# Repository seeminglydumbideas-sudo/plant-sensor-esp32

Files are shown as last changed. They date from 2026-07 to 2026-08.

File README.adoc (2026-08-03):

= plant-sensor-esp32

A low-power Bluetooth Low Energy (BLE) soil moisture sensor node built for the *Seeed Studio XIAO ESP32-C3*.

== Overview

`plant-sensor-esp32` periodically measures soil moisture levels, monitors battery voltage and power source, and broadcasts telemetry over BLE manufacturer advertisements. Designed for battery-powered deployment, the device spends most of its life in ESP32 deep sleep, waking up to sample sensors and advertise data to central receiver nodes (such as the Plant Server).

IMPORTANT: sensors are supposed to be used with a dedicate base station (not used directly with phones). see (todo: link to server ref)

=== Hardware Components

* *Microcontroller:* Seeed Studio XIAO ESP32-C3 (RISC-V single-core @ 160MHz, 2.4GHz Wi-Fi & BLE 5.0)
* *Soil Moisture Sensor:* Capacitive Soil Moisture Sensor v1.2
* *Power Monitoring:* Voltage divider (2x 220kΩ resistors) connected to ADC pin `D2` / `A2`
* *Power Supply:* 3.7V LiPo / Li-Ion battery or USB-C (5V)

== Key Features

* *BLE Telemetry Broadcast:* Broadcasts sensor telemetry without requiring active connections. Scan response manufacturer data payload includes:
** Moisture percentage (`0–100%`, or uncalibrated indicator `0xFF`)
** Raw ADC reading, `rawMin`, and `rawMax` bounds
** Battery voltage (`V`) and power source (Battery vs. USB)
** RTC boot counter
** Filterable by Service UUID `a1b2c3d4-0001-4c9a-8f2e-5a7b9e3d6f80`
* *Capacitive Moisture Sampling:* Non-blocking async sampling state machine to power and sample the sensor safely. Automatically tracks calibration bounds and persists them to NVS flash (`Preferences`).
* *Smart Power Management:* Reads battery voltage via resistor divider on ADC pin `D2`, differentiates between USB and battery power, and controls ESP32 deep sleep cycles. Features a 2-minute safety window on cold power-on to allow seamless firmware reflashing.
* *Calibration Reset:* Press and hold the onboard *BOOT* button (GPIO 9) for 3 seconds to clear saved calibration bounds from flash memory.

== Pinout & Hardware Configuration

[cols="1,1,2", options="header"]
|===
| Component | Pin | Notes

| *Moisture Sensor VCC*
| `D0`
| Switched output to power sensor only during sampling

| *Moisture Sensor Signal*
| `D1`
| Analog input for moisture sensor reading

| *Battery Divider ADC*
| `D2` / `A2`
| Resistor divider input for voltage measurement

| *BOOT Button*
| `GPIO 9`
| Pulled HIGH internally; hold 3s to reset calibration
|===

== Calibration Procedure

The sensor uses automatic bound tracking to calculate soil moisture percentages from raw ADC readings. The bounds (`rawMin` and `rawMax`) are stored in NVS flash memory (`Preferences`). It will persist resets and re-deploy.

To calibrate a sensor:

1. *Wake Device:* Press the *RST button* (or power-cycle the board) to ensure the ESP32 is awake and not in deep sleep mode.
2. *Reset Calibration:* Press and hold the onboard *BOOT button (GPIO 9)* for 3 seconds. The serial output will log `[INFO] Moisture calibration reset`, clearing stored bounds (`rawMin = 4095`, `rawMax = 0`).
3. *Set Dry Bound (0%):* Expose the capacitive probe to dry air (or insert into completely dry soil) during a sample cycle (typically 2-4 minutes). The highest ADC value measured will automatically be saved as `rawMax`.
4. *Set Wet Bound (100%):* Submerge the probe in water up to the max fill line (or insert into fully saturated soil) during a sample cycle. The lowest ADC value measured will automatically be saved as `rawMin`.
5. *Automatic Calculation:* Once `rawMax > rawMin + 500`, the firmware calculates moisture as:
+
[source,cpp]
----
moisture % = 100 - ((100 * (rawValue - rawMin)) / (rawMax - rawMin))
----
+
Updated calibration bounds are saved to flash memory automatically whenever new minimums or maximums are detected.

== Build & Deployment

Use the provided `deploy.sh` script to compile, upload, and monitor:

[source,bash]
----
# Compile and upload specifying the SENSOR_ID
SENSOR_ID=13_rez_ficus ./deploy.sh /dev/ttyACM0

# Compile only
SENSOR_ID=13_rez_ficus ./deploy.sh --compile-only
----

The script automatically generates `Secrets.cpp` containing your specified `SENSOR_ID` and attaches to the serial monitor.

== License

This project is licensed under the MIT License - see the link:LICENSE[LICENSE] file for details.

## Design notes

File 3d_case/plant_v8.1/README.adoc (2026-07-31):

== Plant Sensor V8.1 

* sensor.scad
** moved esp32 3mm down to make the whole smaller
** moved antenna only 2mm down since place due to cable
* holes.scad
** adapt for esp32 new position
* main.scad
** many to adapt to smaller volume

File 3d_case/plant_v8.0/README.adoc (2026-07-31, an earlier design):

== Plant Sensor V8.0

* printed at fablab 21.7.2026
* a bit "bulky", perhaps due to the color (transparent filament)
* once clipped (no screw), hard to take apart due to the screw part to tights.
* plenty space for cables -> can be redude
* sensor a little bit loose -> but differences between PCBs.
* insert walls is hard enough (0.7mm, good) -> wall can be reduced
* evtl. missing guides for antenna?

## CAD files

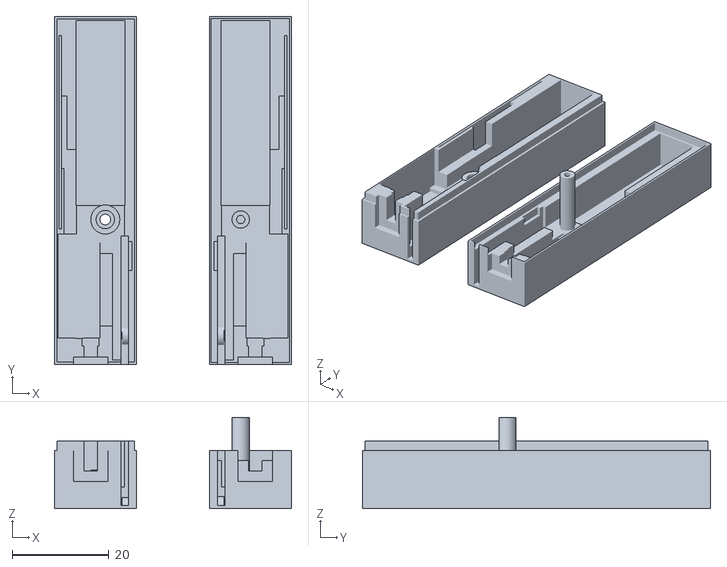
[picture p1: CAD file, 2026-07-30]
3d_case/plant_v7.x/plant_v7.0-thin.stl
49.0 x 72.0 x 18.9

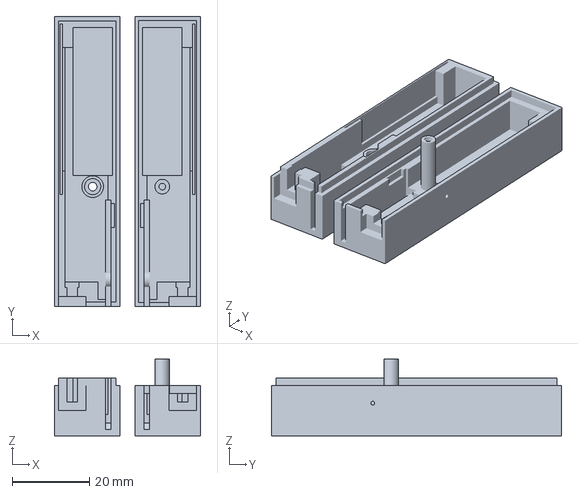
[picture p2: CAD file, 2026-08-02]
3d_case/plant_v8.1/plant_v8.1.3mf
37.8 x 75.0 x 19.9 mm

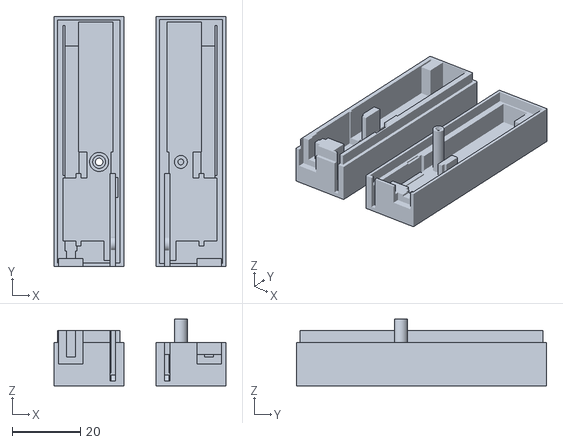
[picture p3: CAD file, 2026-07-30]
3d_case/plant_v7.x/plant_v7.4.stl
50.5 x 73.5 x 19.6

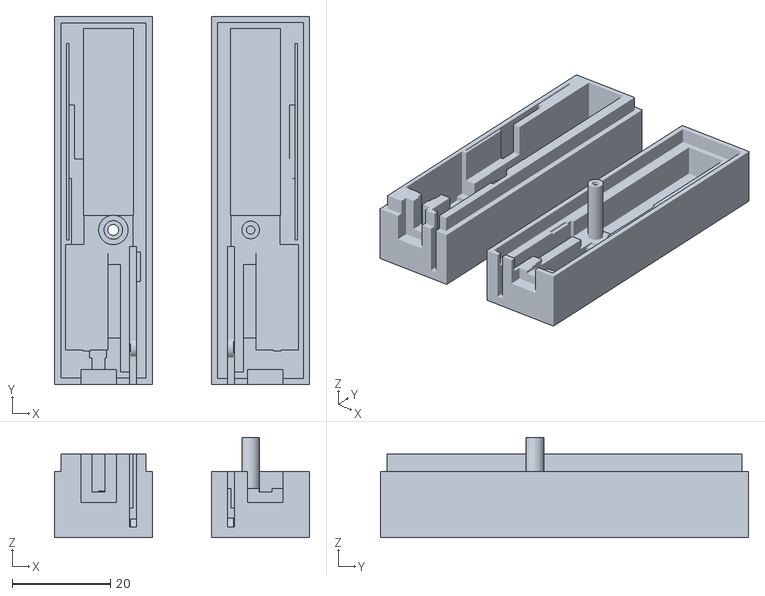
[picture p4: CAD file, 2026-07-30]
3d_case/plant_v7.x/plant_v7.0-fat.stl
52.0 x 75.0 x 20.4

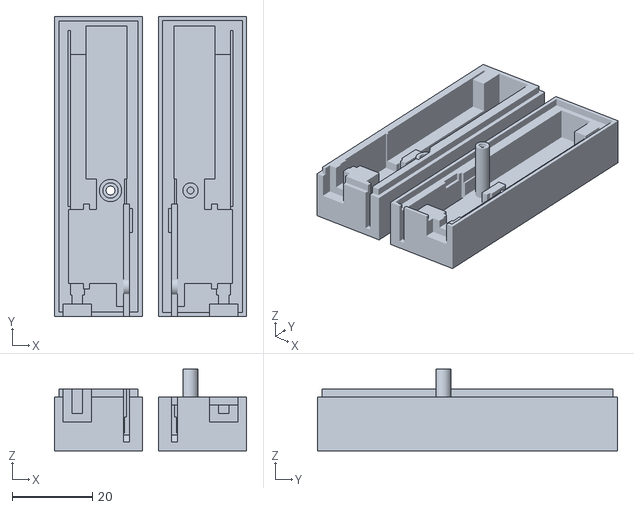
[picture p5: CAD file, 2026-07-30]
3d_case/plant_v8.1/plant_8.0-avoid-thin-walls-2.stl
48.0 x 75.0 x 20.4

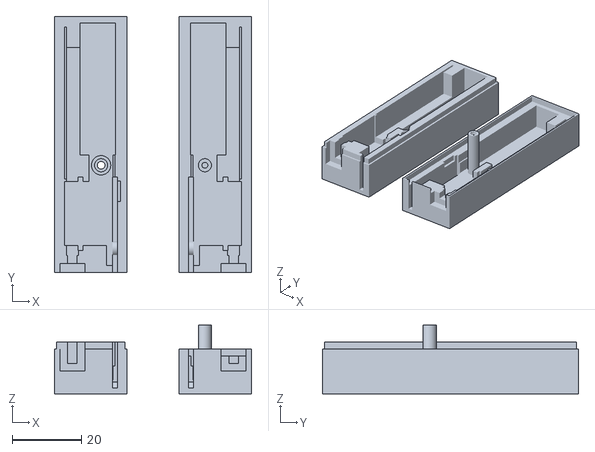
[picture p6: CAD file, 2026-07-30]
3d_case/plant_v8.1/plant_8.0-avoid-thin-walls.stl
57.0 x 74.0 x 19.9

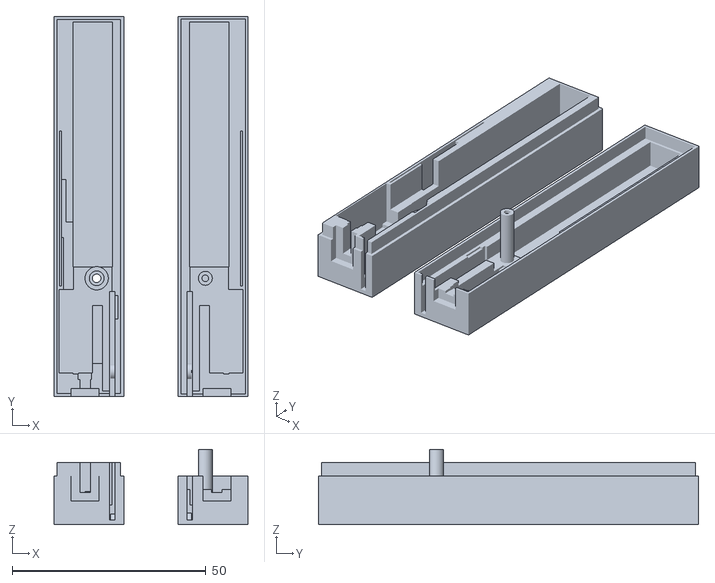
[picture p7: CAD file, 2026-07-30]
3d_case/plant_v7.x/plant_v7.0-large.stl
50.0 x 98.0 x 19.4

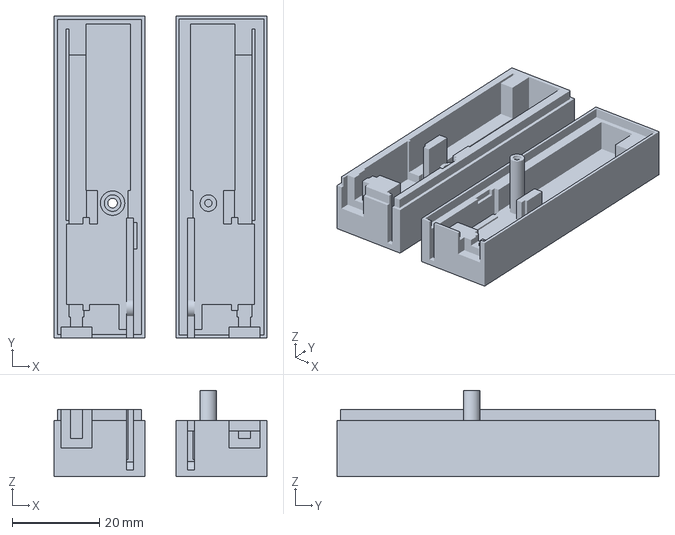
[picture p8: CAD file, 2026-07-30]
3d_case/plant_v7.x/plant_v7.2.3mf
48.9 x 73.9 x 19.8 mm

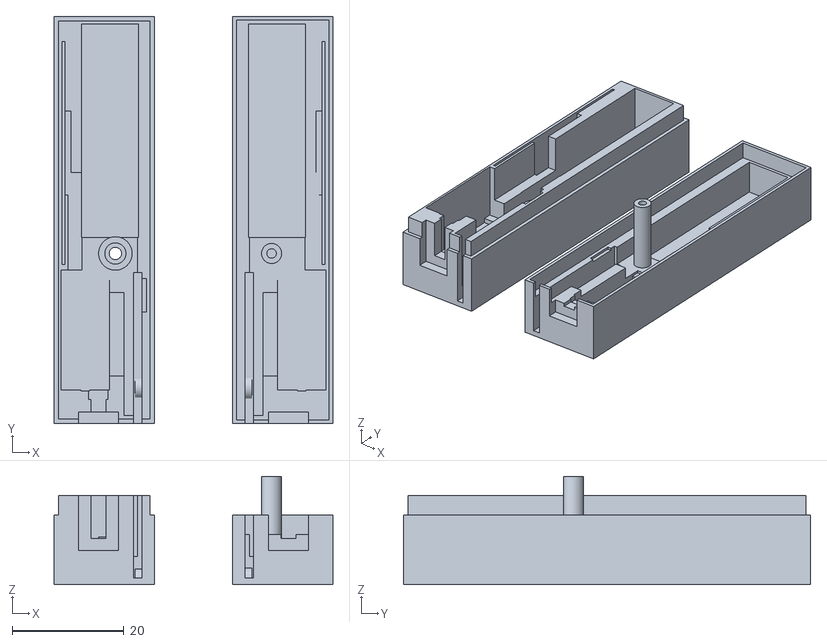
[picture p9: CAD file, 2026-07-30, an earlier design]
3d_case/plant_v7.x/plant_v7.0.stl
50.0 x 73.0 x 19.4

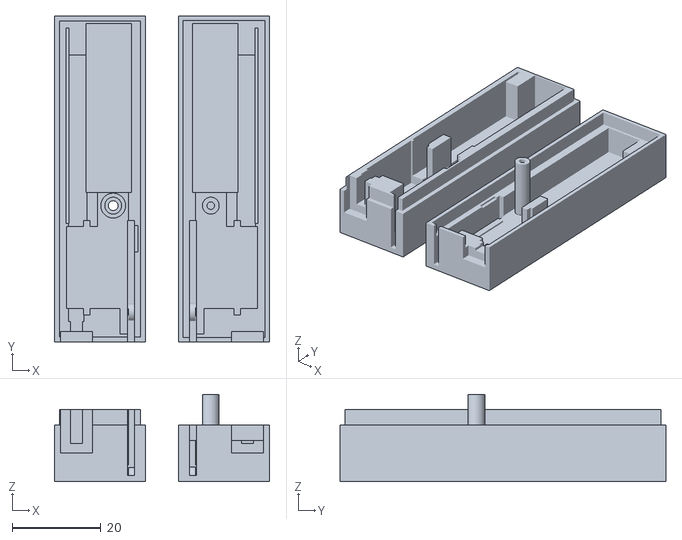
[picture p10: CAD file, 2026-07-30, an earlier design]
3d_case/plant_v7.x/plant_v7.3.stl
48.5 x 73.5 x 19.6

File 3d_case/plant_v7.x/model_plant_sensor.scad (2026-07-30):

use <MCAD/boxes.scad>

//$fn=100;

// large battery 1200mAh : 63
// small battery  600mAh : 38
module battery(length, tol=0) {
    cube([21+tol,length+tol,10+tol],center=true);
}

function inc(arr,tol) = [arr[0]+tol,arr[1]+tol,arr[2]+tol];
function incA(arr,tol) = [arr[0]+tol[0],arr[1]+tol[1],arr[2]+tol[2]];

module esp32(tol=0) {
    pcb=[17.7,21.1,1.3];
    usb=[9,7.3,3.3];
    chip=[13,14,2.1];
    resistors=[17,18,3.6];

    union() {
      // PCB
      cube(inc(pcb, tol), center=true);    
      // USB
      translate([0,-pcb[1]/2+usb[1]/2-1.5,usb[2]/2+pcb[2]/2])
       cube(inc(usb, tol), center=true);    
      // chips
      translate([0,+3.5,chip[2]/2+pcb[2]/2])
       cube(chip, center=true);
      // place for resistors (voltage and battery cables)
      translate([0,0,-resistors[2]/2-pcb[2]/2])
       cube(inc(resistors, tol), center=true);
      // BLE antenna connector
      translate([0,pcb[1]/2,pcb[2]/2+1.5])
       cube(inc([5,5,3], tol), center=true);


    }
}

module antenna(tol=[0,0,0]) {
    union(){        
     cube(incA([22,42,0.5], tol),center=true);
     translate([0,0,-1])        
      cube(incA([10,30,2], tol),center=true);
    }
}

module sensor(tol=0, do_hole=true) {
    pcb=[22.5,97,1.3];
    union() {
      difference() {
        cube(inc(pcb, tol), center=true);    
        if (do_hole) {
          translate([+pcb[0]/2,pcb[1]/2-20.5,0])
            cylinder(6,r=4/2,center=true);
          translate([-pcb[0]/2,pcb[1]/2-20.5,0])
            cylinder(6,r=4/2,center=true);
        }
      }
      // limit line
      translate([0,pcb[1]/2-31,0])
        cube([pcb[0]-8,1,pcb[2]+0.2],center=true);
      // soudures
      translate([0,pcb[1]/2-4,-pcb[2]/2+0.1])
        cube([8,6,2],center=true);
      // chip
      translate([0,pcb[1]/2-13,1.5])
        cube([17,25,2],center=true);
    }
}


module cable(tol=0) {
   translate([0,-4,0])
     cube(inc([8.2,8,2.5],tol),center=true);// usb
   translate([0,-18.9,0])
     cube(inc([12.5,30-4,7],tol),center=true); // plug
}

module model(batt_length, tol=0) {
  translate([0,-45,0])
    sensor(tol);  
    
  translate([0,25,14.3])
    antenna([tol,tol,tol]);    
  translate([0,10+batt_length/2,5])
    battery(batt_length,tol);

  translate([0,0,2]) {
    translate([0,-7,8])
      rotate([0,0,0])
        esp32(tol);
    translate([0,-15.6,10.3])
      cable(tol);
  }
}


batS=38;
batL=63;
model(batS);

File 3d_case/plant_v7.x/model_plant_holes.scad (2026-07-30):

use <model_plant_sensor.scad>

// ================
// holes
// ================
module hole_ESP() {
   translate([0,0,2]) {
    union(){
     translate([0,-7,6.5])
       rotate([0,0,0]) {
        cube([18,18.5,12.1],center=true);
        //translate([0,0.3,0])
        // cube([16,21.5,12],center=true);
        translate([0,0,1.5])
         esp32(0.2);
       };
      translate([0,-15.6,10.3])
      cable(0.2);
    }        
  }
}

module hole_model(batt_length) {  
  // esp+cable
  hole_ESP();
  // sensor
  translate([0,-45,0])
    sensor(0.2, false);  
  // hole esp32-sensor
  //translate([0,0,25])
  //  cube([10,20,10],center=true);
  // battery
  translate([0,10+batt_length/2,5])
    battery(batt_length,0.2);    
  // hole battery-(sensor_esp32)
  translate([0,6,4])
    cube([18,10,7],center=true);
  // antenna
  translate([0,25,14.3])
    antenna([1,2,0.2]);        
  // hole antenna-*
  translate([0,21,12])
    cube([13.4,40,4.1],center=true);
}

color("#f0a090",0.5)
  hole_model(63);
color("#a09090",0.5)
  model(63);

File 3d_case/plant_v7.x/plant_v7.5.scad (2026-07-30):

use <MCAD/boxes.scad>
use <model_plant_sensor.scad>
use <model_plant_holes.scad>

/*[ Rendering ]*/
//poly quality
$fn=100; // [100:high,6:low]

//Type of battery (lenght)
_batLg=38; // [38:600mAh (small),63:1200mAh (large)]
// Volume Increased
_vol_inc=0.5;// [-2:0.1:5]
// Edge Depth
_edge_depth=3.5;// [1:0.25:10]
// Edge Border
_edge_width=1;// [0.1:0.1:3]

// Opening
_opening=20;// [0:1:60]

// Left
_left=true;
// Right
_right=true;
// Model
_model=true;
// Model
_print=false;



// ================
// VOL
// ================
module right_insert(main_pos,main_vol,edge_depth,edge_width,tol=0) {
 translate([
    main_pos[0],
    main_pos[1],
    main_pos[2]]){
  cube([
    edge_depth*2,
    main_vol[1]-2*edge_width-2*tol,
    main_vol[2]-2*edge_width-2*tol],center=true);
 }
}

module volume_right(main_pos,main_vol,edge_depth,edge_width,tol=0) {
 // main volume
 difference() {
  translate(main_pos){
   cube(main_vol,center=true);
  };
  // remove left side
  translate([main_pos[0]+100,0,0]){
   cube([200,200,200],center=true);
  };
 }
 // "right insert": the part that is smaller 
 // and go inside case_left
 right_insert(main_pos,main_vol,edge_depth,edge_width,tol); 
}

module volume_left(main_pos,main_vol,edge_depth,edge_width) {
 // main volume
 difference() {
  translate(main_pos){
   cube(main_vol,center=true);
  };
  // remove left side
  translate([main_pos[0]-100,0,0]){
   cube([200,200,100],center=true);
  };
  // make place for the "right insert" () see case_right()
  right_insert(main_pos,main_vol,edge_depth, edge_width, 0);
 }
}



// ================
// CASE
// ================

module hole_screw_m2() {
  // hole for thread
  //translate([-2,7,-3])
  translate([0,0,-3.6])
   cylinder(h=8,r=1.7/2,center=true);
  // hole no thread
  translate([0,0,-8.5]) 
   cylinder(h=2,r=2.2/2,center=true);
  // hole for head
  translate([0,0,-12.5]) 
   cylinder(h=8,r=3.4/2,center=true);
}

SCREW_Z=4;

module case_left(main_pos,main_vol,edge_depth,edge_width,battery_length) {    
 // volume - hole
 difference() {    
    volume_left(main_pos,main_vol,edge_depth,edge_width);
    hole_model(battery_length);
 } 
 // things to hold sensor
 difference() {
  translate([11.5,-17,-0.5])
   cylinder(h=4,r=2,center=true);
  translate([14,-17,0])
   cube([5,5,5], center=true);
 }
 // long stuff for screw - screw hole
 translate([1.1,7,SCREW_Z])
   rotate([0,90,0])
     difference() {
       cylinder(h=16,r=1.9,center=true);
       hole_screw_m2();
     }         
}

module case_right(main_pos,main_vol,edge_depth,edge_width,edge_tol,battery_length) {
 // volume-holes-hole_screw    
 difference() {
    volume_right(main_pos,main_vol,edge_depth,edge_width,edge_tol);
    hole_model(battery_length);
    translate([0.6,7,SCREW_Z])
     rotate([0,90,0])
       hole_screw_m2();
 } 
 // things to hold sensor
 difference() {
  translate([-11.5,-17,-0.5])
   cylinder(h=4,r=1.9,center=true);
  translate([-14,-17,0])
   cube([5,5,5], center=true);
 }
 // hole for screw (with head stop)
 difference() { 
  translate([-8,7,SCREW_Z])
   rotate([0,90,0])
     cylinder(h=8,r=2.8,center=true);
   //cube([6,5.8,5.5],center=true);   
   // remove hole for screw
   translate([0.6,7,SCREW_Z])
     rotate([0,90,0])
       hole_screw_m2();
   // remove insert for long stuf
   translate([0.5,7,SCREW_Z])
     rotate([0,90,0])
      cylinder(h=15,r=1.9,center=true);
 }

}
// ================
// DEBUG
// ================
module view_left_case(batLg) {
 color("#c0c0c0")
  model(batLg);
 case_left(_pos,_vol,_edge_depth,_edge_width,batLg);    
}

module view_right_case(batLg) {
 color("#c0c0c0")
  model(batLg);
 case_right(_pos,_vol,_edge_depth,_edge_width,_edge_tol,batLg);  
}

module view_both_cases(pos,vol,ed,ew,et,bl,space,space=20) {
 if (_right)
   translate([-space,0,0])
    color("#a060a0",1)
     case_right(pos,vol,ed,ew,et,bl);    
 if (_left)
  translate([space,0,0])
   color("#60a0a0",1)
    case_left(pos,vol,ed,ew,bl);
}
    
module view_up(pos,vol,ed,ew,et,bl,space,cut) {
 difference() {
  view_both_cases(pos,vol,ed,ew,et,bl,space);
  translate([-150,-150,cut]) 
   cube([300,300,300]);
 }
}

module view_print(pos,vol,ed,ew,et,bl,space) {
 rotate([0,-90,0])
  translate([10,0,space])
   color("#a060a0",1)
    case_right(pos,vol,ed,ew,et,bl);    
 rotate([0,90,0])
  translate([-10,0,space])
    color("#60a0a0",1)
     case_left(pos,vol,ed,ew,bl);
}

// ================
// MAIN
// ================

_pos=[0 , -6+_batLg/2, 7];
_vol=[25, 35+_batLg,  20];
_edge_tol=0.1;

// DEBUG insert only
//volume_right(_pos,_vol,_edge_depth,_edge_width,_edge_tol); 
//volume_left(_pos,_vol,_edge_depth,_edge_width);

// DEBUG cuts
//view_up(_pos,_vol,_edge_depth,_edge_width,_edge_tol,_batLg, 0, SCREW_Z); // focus: screw
//view_up(_pos,_vol,_edge_depth,_edge_width,_edge_tol,_batLg, 0, 10); // focus: ??
//view_up(_pos,_vol,_edge_depth,_edge_width,_edge_tol,_batLg, 0, 0); // focus: sensor



// Normal view 
if (_right || _left) view_both_cases(_pos,inc(_vol,_vol_inc),_edge_depth,_edge_width,_edge_tol,_batLg, _opening);
if (_print)
    view_print(_pos,inc(_vol,_vol_inc),_edge_depth,_edge_width,_edge_tol,_batLg, _opening);

 if (_model)
  color("#a09090",0.5)
    model(_batLg);

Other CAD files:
3d_case/plant_v8.1/plant_8.1.stl
3d_case/plant_v7.x/plant_v7.3.gcode.3mf
3d_case/plant_v7.x/plant_v7.5-avoid_thin_walls.stl
3d_case/plant_v8.1/plant_v8.0.3mf
3d_case/plant_v7.x/plant_v7.4-avoid_thin_walls.stl
3d_case/plant_v7.x/plant_v7.2.gcode.3mf
3d_case/plant_v8.1/sensor.scad
3d_case/plant_v7.x/plant_v7.0.scad
3d_case/plant_v7.x/plant_v7.1.scad
3d_case/plant_v7.x/plant_v7.2.scad
3d_case/plant_v7.x/plant_v7.2.stl
3d_case/plant_v7.x/plant_v7.3.scad
3d_case/plant_v7.x/plant_v7.4.scad
3d_case/plant_v8.0/holes.scad
3d_case/plant_v8.0/main-plant-sensor.scad
3d_case/plant_v8.1/holes.scad
3d_case/plant_v8.1/main.scad

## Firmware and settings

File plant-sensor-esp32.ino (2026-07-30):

#include <Arduino.h>
#include "Secrets.h"
#include "PowerManager.h"
#include "Moisture.h"
#include "Blues.h"
#include "Sensor.h"
#include "BootButton.h"

/*

Code written for esp32:esp32:XIAO_ESP32C3.

See README.adoc and deploy.sh for details.
*/

// globbal variables
PowerManager power;
Moisture moisture;
BlueS bluetooth;
Sensor sensor(bluetooth, moisture, power);
BootButton bootButton(moisture);

// =========================
// Setup (run once on boot)
// =========================
void setup(void) {  
  // init Serial for debug output
  Serial.begin(115200);
  //Serial.setDebugOutput(true);  

  // modules
  power.init();
  moisture.init();
  bluetooth.init();
  sensor.init();
  bootButton.init();
}

// =========================
// Main loop
// =========================
void loop(void) {
  power.loop();
  moisture.loop();
  bluetooth.loop();
  sensor.loop();
  bootButton.loop();
  delay(500);
}

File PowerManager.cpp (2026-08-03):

#include <Arduino.h>
#include <esp_sleep.h>
#include <BLEDevice.h>
#include "PowerManager.h"
#include "Config.h"

/*
Use 2x220k resistor on an analog port to read voltage value (battery or USB)
ref: https://wiki.seeedstudio.com/check_battery_voltage/
*/

// RTC RAM variables: survive deep sleep, reset on cold power cycle.
RTC_DATA_ATTR int bootCount = 0;
RTC_DATA_ATTR uint32_t totalElapsedSec = 0;

float PowerManager::getLevel() {
  uint32_t Vbatt = 0;
  for (int i = 0; i < 16; i++) {
    Vbatt += analogReadMilliVolts(D2); // ADC with correction
  }
  return 2 * Vbatt / 16 / 1000.0; // attenuation ratio 1/2, mV --> V
}

int PowerManager::checkSource() {
  return getLevel() > 4.1 ? POWER_USB : POWER_BAT;
}

int PowerManager::getBootCount() const {
  return bootCount;
}

uint32_t PowerManager::getTotalElapsedSec() const {
  return totalElapsedSec;
}

void PowerManager::_incBootCount() {
  bootCount++;
}

void PowerManager::init() {
  Serial.printf("[INFO ] Boot #%d (total elapsed: %lu min / %lu sec)\n",
                getBootCount(), (unsigned long)(getTotalElapsedSec() / 60), (unsigned long)getTotalElapsedSec());
  pinMode(A2, INPUT); // ADC on port D2
  _dataReady  = false;
  _calibrated = false;
  _printWakeupReason();
  _incBootCount();
}

SleepMode PowerManager::getSleepMode() const {
  if (getBootCount() == 1 && millis() < REFLASH_SAFETY_WINDOW_MS) {
    return SleepMode::REFLASH_SAFETY_DELAY;
  }
  if (getTotalElapsedSec() < SHORT_SLEEP_WINDOW_SEC) {
    return SleepMode::SHORT_DEEP_SLEEP;
  }
  return SleepMode::LONG_DEEP_SLEEP;
}

void PowerManager::notifyDataReady(bool calibrated) {
  _dataReady   = true;
  _dataReadyAt = millis();
  _calibrated  = calibrated;
}

#define BROADCAST_WINDOW_MS (10 * 1000UL) // stay awake for clients to scan

void PowerManager::loop() {
  if (!_calibrated) return; // sensor not yet calibrated — stay awake
  if (!_dataReady)  return; // no reading ready yet
  if (millis() - _dataReadyAt < BROADCAST_WINDOW_MS) return; // broadcast window
  _dataReady = false;

  switch (getSleepMode()) {
    case SleepMode::REFLASH_SAFETY_DELAY:
      _handleReflashSafetyDelay(SHORT_SLEEP_DURATION_SEC);
      break;
    case SleepMode::SHORT_DEEP_SLEEP:
      _enterHardwareDeepSleep(SHORT_SLEEP_DURATION_SEC);
      break;
    case SleepMode::LONG_DEEP_SLEEP:
      _enterHardwareDeepSleep(LONG_SLEEP_DURATION_SEC);
      break;
  }
}

void PowerManager::_handleReflashSafetyDelay(unsigned long seconds) {
  unsigned long remaining = (millis() < REFLASH_SAFETY_WINDOW_MS)
                          ? (REFLASH_SAFETY_WINDOW_MS - millis()) / 1000
                          : 0;
  Serial.printf("[INFO ] [REFLASH_SAFETY_DELAY] Delaying %lus (reflash window: %lus left)\n", seconds, remaining);

  // Stop BLE advertising to simulate deep sleep during this delay
  BLEDevice::getAdvertising()->stop();

  // Accumulate delay into total elapsed time
  totalElapsedSec += seconds;

  delay(seconds * 1000);
}

void PowerManager::_enterHardwareDeepSleep(unsigned long seconds) {
  if (seconds >= 60) {
    Serial.printf("[INFO ] [%s] Entering hardware deep sleep for %ldmin (elapsed: %lu min / %lu min window)\n",
                  getSleepMode() == SleepMode::SHORT_DEEP_SLEEP ? "SHORT_DEEP_SLEEP" : "LONG_DEEP_SLEEP",
                  seconds / 60, (unsigned long)(getTotalElapsedSec() / 60), (unsigned long)(SHORT_SLEEP_WINDOW_SEC / 60));
  } else {
    Serial.printf("[INFO ] [%s] Entering hardware deep sleep for %lusec (elapsed: %lusec)\n",
                  getSleepMode() == SleepMode::SHORT_DEEP_SLEEP ? "SHORT_DEEP_SLEEP" : "LONG_DEEP_SLEEP",
                  seconds, (unsigned long)getTotalElapsedSec());
  }

  // Accumulate active runtime + sleep duration into RTC time tracking
  totalElapsedSec += (millis() / 1000) + seconds;

  esp_sleep_enable_timer_wakeup(seconds * 1000000ULL);
  delay(100); // flush serial output before sleeping
  esp_deep_sleep_start();
}

void PowerManager::_printWakeupReason() {
  esp_sleep_wakeup_cause_t reason = esp_sleep_get_wakeup_cause();
  switch (reason) {
    case ESP_SLEEP_WAKEUP_EXT0:     Serial.println("[DEBUG] Wakeup caused by external signal using RTC_IO"); break;
    case ESP_SLEEP_WAKEUP_EXT1:     Serial.println("[DEBUG] Wakeup caused by external signal using RTC_CNTL"); break;
    case ESP_SLEEP_WAKEUP_TIMER:    Serial.println("[DEBUG] Wakeup caused by timer"); break;
    case ESP_SLEEP_WAKEUP_TOUCHPAD: Serial.println("[DEBUG] Wakeup caused by touchpad"); break;
    case ESP_SLEEP_WAKEUP_ULP:      Serial.println("[DEBUG] Wakeup caused by ULP program"); break;
    default: Serial.printf("[DEBUG] Wakeup was not caused by deep sleep: %d\n", reason); break;
  }
}

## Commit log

2026-07-30 inital commit
    [holes.scad, main.scad, model_plant_holes.scad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]
2026-07-31 update case
    [holes.scad, main-plant-sensor.scad, main.scad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]
2026-08-01 reset hole
    [main.scad]
